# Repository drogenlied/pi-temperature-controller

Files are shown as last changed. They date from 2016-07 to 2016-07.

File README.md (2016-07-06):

# Pi temperature controller
A Raspberry Pi based H-bridge controller designed to stabilize temperatures in an optics lab

## Hardware
  * Raspberry Pi (Model 2 recommended)
  * Measurement Specialities TSYS01 temperature sensor
  * Adum 14xx isolators between control and driver
  * VNH3SP30 H-bridge driver for output
  
## Features
  * Can control Peltier elements as well as resistive heaters for temperature stabilisation.
  * Fabrication should be possible in every university PCB shop
  * Hand soldering is possible but reflowing the VNH3SP30 is recommended
  
## Software
Test software is in this repository but https://github.com/Ulm-IQO/qudi is recommended for operation.

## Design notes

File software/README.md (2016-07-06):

Required python modules:
  * spidev
  * i2cdev
  * RPi.GPIO

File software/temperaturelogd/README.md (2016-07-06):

# Modules

## Required Python 3 modules:
  * spidev
  * i2cdev
  * statistics

## optional:
  * influxdb

# /etc
Files in the etc folder need to have their paths modified to work for you!

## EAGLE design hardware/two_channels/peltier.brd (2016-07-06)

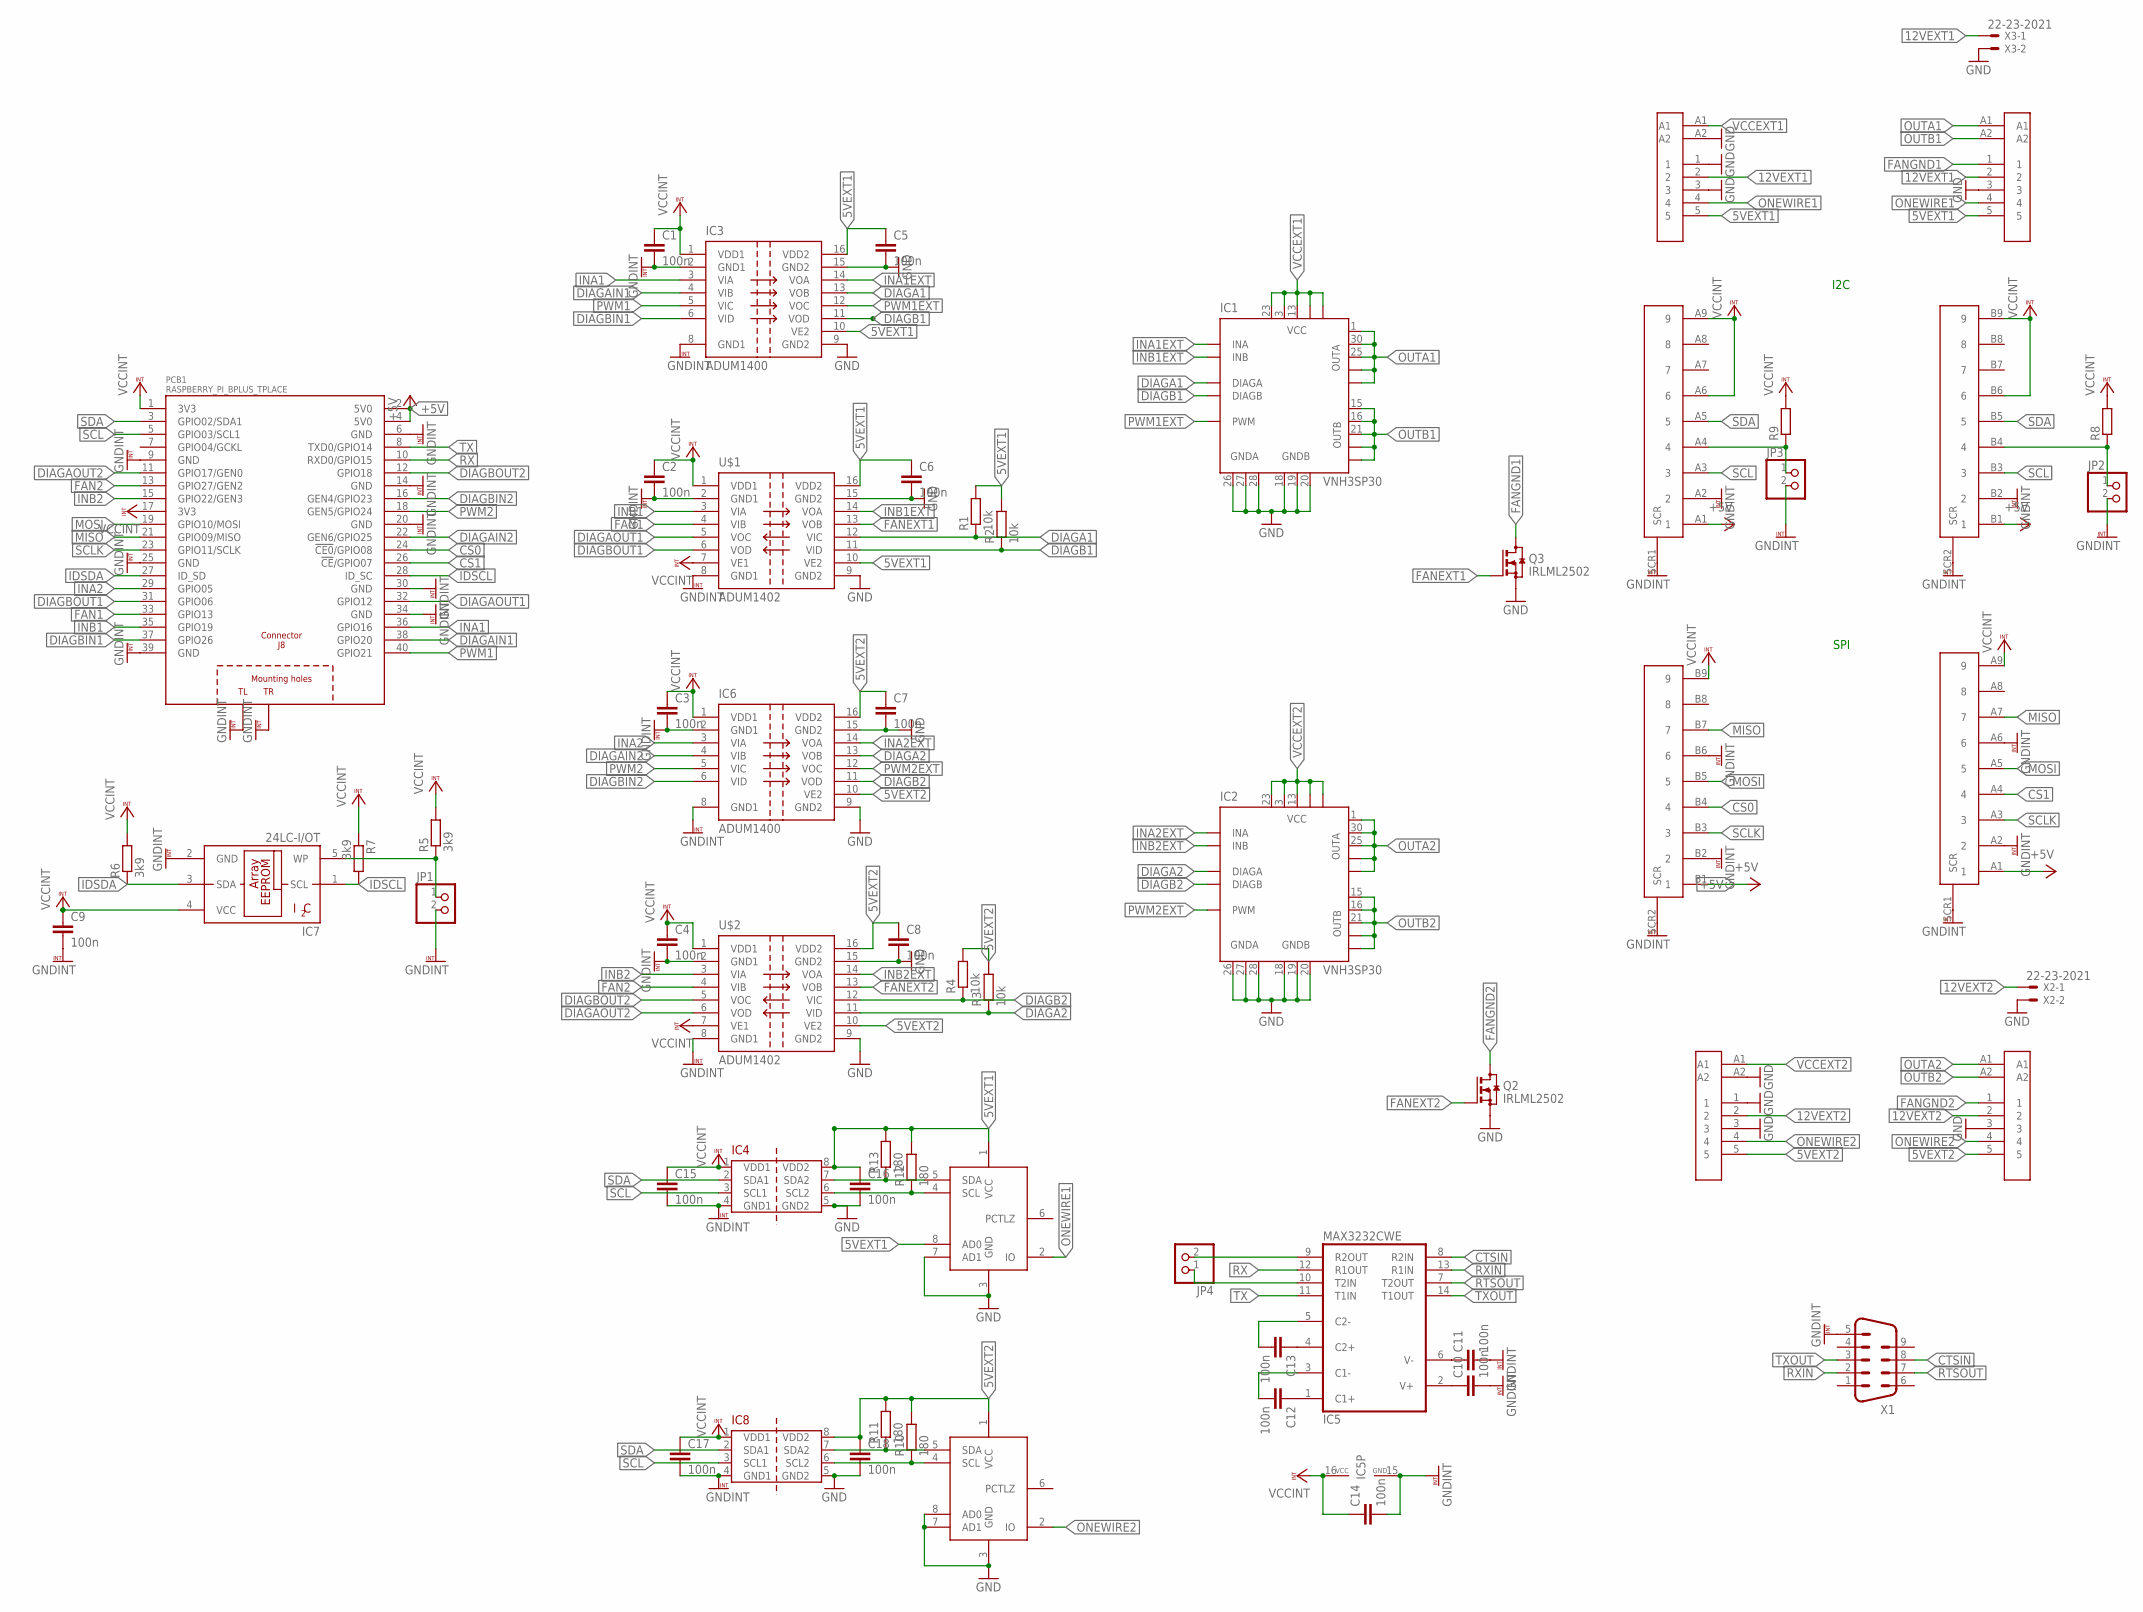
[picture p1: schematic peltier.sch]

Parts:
C1, C2, C3, C4, C5, C6, C7, C8, C9, C10, C11, C12, C13, C14, C15, C16, C17, C18: 100n; C0805
IC1, IC2: VNH3SP30; MULTIPOWERSO-30
IC3, IC6: ADUM1400; SO16W
IC4, IC8: ADUM1250; SO08
IC5: MAX3232CWE; SO16L
IC7: 24LC-I/OT; SOT23-5
JP1, JP2, JP3, JP4: PINHD-1X2; 1X02
PCB1: RASPBERRY_PI_BPLUS_TPLACE
Q2, Q3: IRLML2502; SOT23
R1, R2, R3, R4: 10k; R0805
R5, R6, R7: 3k9; R0805
R8, R9: R-EU_R0805; R0805
R10, R11, R12, R13: 180; R0805
U$1, U$2: ADUM1402; SO16W
U$3, U$4: 7W2-F
U$5, U$6: 7W2-M
U$11, U$12: 164A19919X
U$14, U$15: DS2483-100; SO-08
X1: M09HP
X2, X3: 22-23-2021

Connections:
5VEXT1: C5.1, C6.1, C16.1, IC3.10 (VE2), IC3.16 (VDD2), IC4.8 (VDD2), R1.2, R2.2, R12.2, R13.2, U$1.10 (VE2), U$1.16 (VDD2), U$3.5, U$5.5, U$14.1 (VCC), U$14.8 (AD0)
5VEXT2: C7.1, C8.1, C18.1, IC6.10 (VE2), IC6.16 (VDD2), IC8.8 (VDD2), R3.2, R4.2, R10.2, R11.2, U$2.10 (VE2), U$2.16 (VDD2), U$4.5, U$6.5, U$15.1 (VCC)
12VEXT1: U$3.2, U$5.2, X3.1
12VEXT2: U$4.2, U$6.2, X2.1
+5V: PCB1.2 (5V0), PCB1.4 (5V0), U$11.A1 (1), U$11.B1 (1), U$12.A1 (1), U$12.B1 (1)
CS0: PCB1.24 (!CE0!/GPIO08), U$12.B4 (4)
CS1: PCB1.26 (!CE!/GPIO07), U$12.A4 (4)
CTSIN: IC5.8 (R2IN), X1.8
DIAGA1: IC1.6 (DIAGA), IC3.13 (VOB), R1.1, U$1.12 (VIC)
DIAGA2: IC2.6 (DIAGA), IC6.13 (VOB), R3.1, U$2.11 (VID)
DIAGAIN1: IC3.4 (VIB), PCB1.38 (GPIO20)
DIAGAIN2: IC6.4 (VIB), PCB1.22 (GEN6/GPIO25)
DIAGAOUT1: PCB1.32 (GPIO12), U$1.5 (VOC)
DIAGAOUT2: PCB1.11 (GPIO17/GEN0), U$2.6 (VOD)
DIAGB1: IC1.10 (DIAGB), IC3.11 (VOD), R2.1, U$1.11 (VID)
DIAGB2: IC2.10 (DIAGB), IC6.11 (VOD), R4.1, U$2.12 (VIC)
DIAGBIN1: IC3.6 (VID), PCB1.37 (GPIO26)
DIAGBIN2: IC6.6 (VID), PCB1.16 (GEN4/GPIO23)
DIAGBOUT1: PCB1.31 (GPIO06), U$1.6 (VOD)
DIAGBOUT2: PCB1.12 (GPIO18), U$2.5 (VOC)
FAN1: PCB1.33 (GPIO13), U$1.4 (VIB)
FAN2: PCB1.13 (GPIO27/GEN2), U$2.4 (VIB)
FANEXT1: Q3.1 (G), U$1.13 (VOB)
FANEXT2: Q2.1 (G), U$2.13 (VOB)
FANGND1: Q3.3 (D), U$3.1
FANGND2: Q2.3 (D), U$4.1
GND: C5.2, C6.2, C7.2, C8.2, C16.2, C18.2, IC1.18 (GNDB), IC1.19 (GNDB), IC1.20 (GNDB), IC1.26 (GNDA), IC1.27 (GNDA), IC1.28 (GNDA), IC2.18 (GNDB), IC2.19 (GNDB), IC2.20 (GNDB), IC2.26 (GNDA), IC2.27 (GNDA), IC2.28 (GNDA), IC3.9 (GND2), IC3.15 (GND2), IC4.5 (GND2), IC6.9 (GND2), IC6.15 (GND2), IC8.5 (GND2), Q2.2 (S), Q3.2 (S), U$1.9 (GND2), U$1.15 (GND2), U$2.9 (GND2), U$2.15 (GND2), U$3.3, U$4.3, U$5.1, U$5.3, U$5.A2, U$6.1, U$6.3, U$6.A2, U$14.3 (GND), U$14.7 (AD1), U$15.3 (GND), U$15.7 (AD1), U$15.8 (AD0), X2.2, X3.2
GNDINT: C1.2, C2.2, C3.2, C4.2, C9.2, C10.2, C11.2, C14.2, C15.2, C17.2, IC3.2 (GND1), IC3.8 (GND1), IC4.4 (GND1), IC5.15 (GND), IC6.2 (GND1), IC6.8 (GND1), IC7.2 (GND), IC8.4 (GND1), JP1.2, JP2.2, JP3.2, PCB1.6 (GND), PCB1.9 (GND), PCB1.14 (GND), PCB1.20 (GND), PCB1.25 (GND), PCB1.30 (GND), PCB1.34 (GND), PCB1.39 (GND), PCB1.PE_TL (TL), PCB1.PE_TR (TR), U$1.2 (GND1), U$1.8 (GND1), U$2.2 (GND1), U$2.8 (GND1), U$11.A2 (2), U$11.B2 (2), U$11.SCR1 (SCR), U$11.SCR2 (SCR), U$12.A2 (2), U$12.A6 (6), U$12.B2 (2), U$12.B6 (6), U$12.SCR1 (SCR), U$12.SCR2 (SCR), X1.5
IDSCL: IC7.1 (SCL), PCB1.28 (ID_SC), R7.2
IDSDA: IC7.3 (SDA), PCB1.27 (ID_SD), R6.1
INA1: IC3.3 (VIA), PCB1.36 (GPIO16)
INA1EXT: IC1.5 (INA), IC3.14 (VOA)
INA2: IC6.3 (VIA), PCB1.29 (GPIO05)
INA2EXT: IC2.5 (INA), IC6.14 (VOA)
INB1: PCB1.35 (GPIO19), U$1.3 (VIA)
INB1EXT: IC1.11 (INB), U$1.14 (VOA)
INB2: PCB1.15 (GPIO22/GEN3), U$2.3 (VIA)
INB2EXT: IC2.11 (INB), U$2.14 (VOA)
MISO: PCB1.21 (GPIO09/MISO), U$12.A7 (7), U$12.B7 (7)
MOSI: PCB1.19 (GPIO10/MOSI), U$12.A5 (5), U$12.B5 (5)
unnamed: IC7.5 (WP), JP1.1, R5.1
unnamed: JP3.1, R9.1, U$11.A4 (4)
unnamed: JP2.1, R8.1, U$11.B4 (4)
unnamed: C10.1, IC5.2 (V+)
unnamed: C11.1, IC5.6 (V-)
unnamed: C12.1, IC5.1 (C1+)
unnamed: C12.2, IC5.3 (C1-)
unnamed: C13.1, IC5.4 (C2+)
unnamed: C13.2, IC5.5 (C2-)
unnamed: IC5.9 (R2OUT), JP4.2
unnamed: IC5.10 (T2IN), JP4.1
unnamed: IC4.7 (SDA2), R13.1, U$14.5 (SDA)
unnamed: IC4.6 (SCL2), R12.1, U$14.4 (SCL)
unnamed: IC8.7 (SDA2), R11.1, U$15.5 (SDA)
unnamed: IC8.6 (SCL2), R10.1, U$15.4 (SCL)
ONEWIRE1: U$3.4, U$5.4, U$14.2 (IO)
ONEWIRE2: U$4.4, U$6.4, U$15.2 (IO)
OUTA1: IC1.1 (OUTA), IC1.25 (OUTA), IC1.30 (OUTA), IC1.OUTA, IC1.OUTA@1 (OUTA), U$3.A1
OUTA2: IC2.1 (OUTA), IC2.25 (OUTA), IC2.30 (OUTA), IC2.OUTA, IC2.OUTA@1 (OUTA), U$4.A1
OUTB1: IC1.15 (OUTB), IC1.16 (OUTB), IC1.21 (OUTB), IC1.OUTB, IC1.OUTB@1 (OUTB), U$3.A2
OUTB2: IC2.15 (OUTB), IC2.16 (OUTB), IC2.21 (OUTB), IC2.OUTB, IC2.OUTB@1 (OUTB), U$4.A2
PWM1: IC3.5 (VIC), PCB1.40 (GPIO21)
PWM1EXT: IC1.8 (PWM), IC3.12 (VOC)
PWM2: IC6.5 (VIC), PCB1.18 (GEN5/GPIO24)
PWM2EXT: IC2.8 (PWM), IC6.12 (VOC)
RTSOUT: IC5.7 (T2OUT), X1.7
RX: IC5.12 (R1OUT), PCB1.10 (RXD0/GPIO15)
RXIN: IC5.13 (R1IN), X1.2
SCL: IC4.3 (SCL1), IC8.3 (SCL1), PCB1.5 (GPIO03/SCL1), U$11.A3 (3), U$11.B3 (3)
SCLK: PCB1.23 (GPIO11/SCLK), U$12.A3 (3), U$12.B3 (3)
SDA: IC4.2 (SDA1), IC8.2 (SDA1), PCB1.3 (GPIO02/SDA1), U$11.A5 (5), U$11.B5 (5)
TX: IC5.11 (T1IN), PCB1.8 (TXD0/GPIO14)
TXOUT: IC5.14 (T1OUT), X1.3
VCCEXT1: IC1.3 (VCC), IC1.13 (VCC), IC1.23 (VCC), IC1.VCC, IC1.VCC@1 (VCC), U$5.A1
VCCEXT2: IC2.3 (VCC), IC2.13 (VCC), IC2.23 (VCC), IC2.VCC, IC2.VCC@1 (VCC), U$6.A1
VCCINT: C1.1, C2.1, C3.1, C4.1, C9.1, C14.1, C15.1, C17.1, IC3.1 (VDD1), IC4.1 (VDD1), IC5.16 (VCC), IC6.1 (VDD1), IC7.4 (VCC), IC8.1 (VDD1), PCB1.1 (3V3), PCB1.17 (3V3), R5.2, R6.2, R7.1, R8.2, R9.2, U$1.1 (VDD1), U$1.7 (VE1), U$2.1 (VDD1), U$2.7 (VE1), U$11.A6 (6), U$11.A9 (9), U$11.B6 (6), U$11.B9 (9), U$12.A9 (9), U$12.B9 (9)

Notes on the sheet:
I2C
SPI

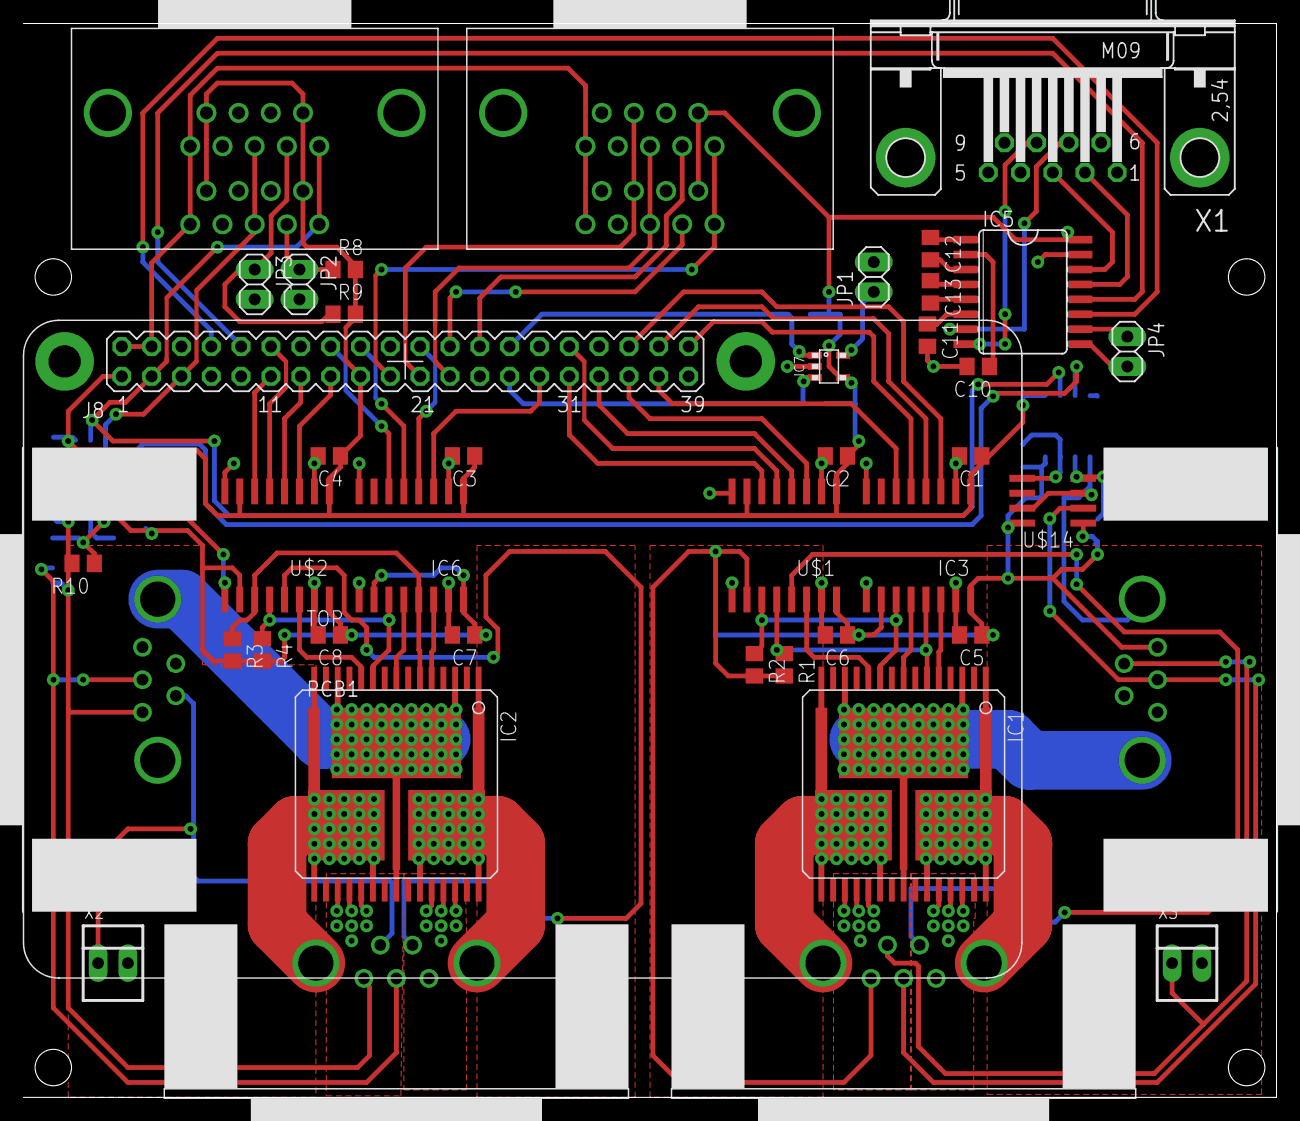
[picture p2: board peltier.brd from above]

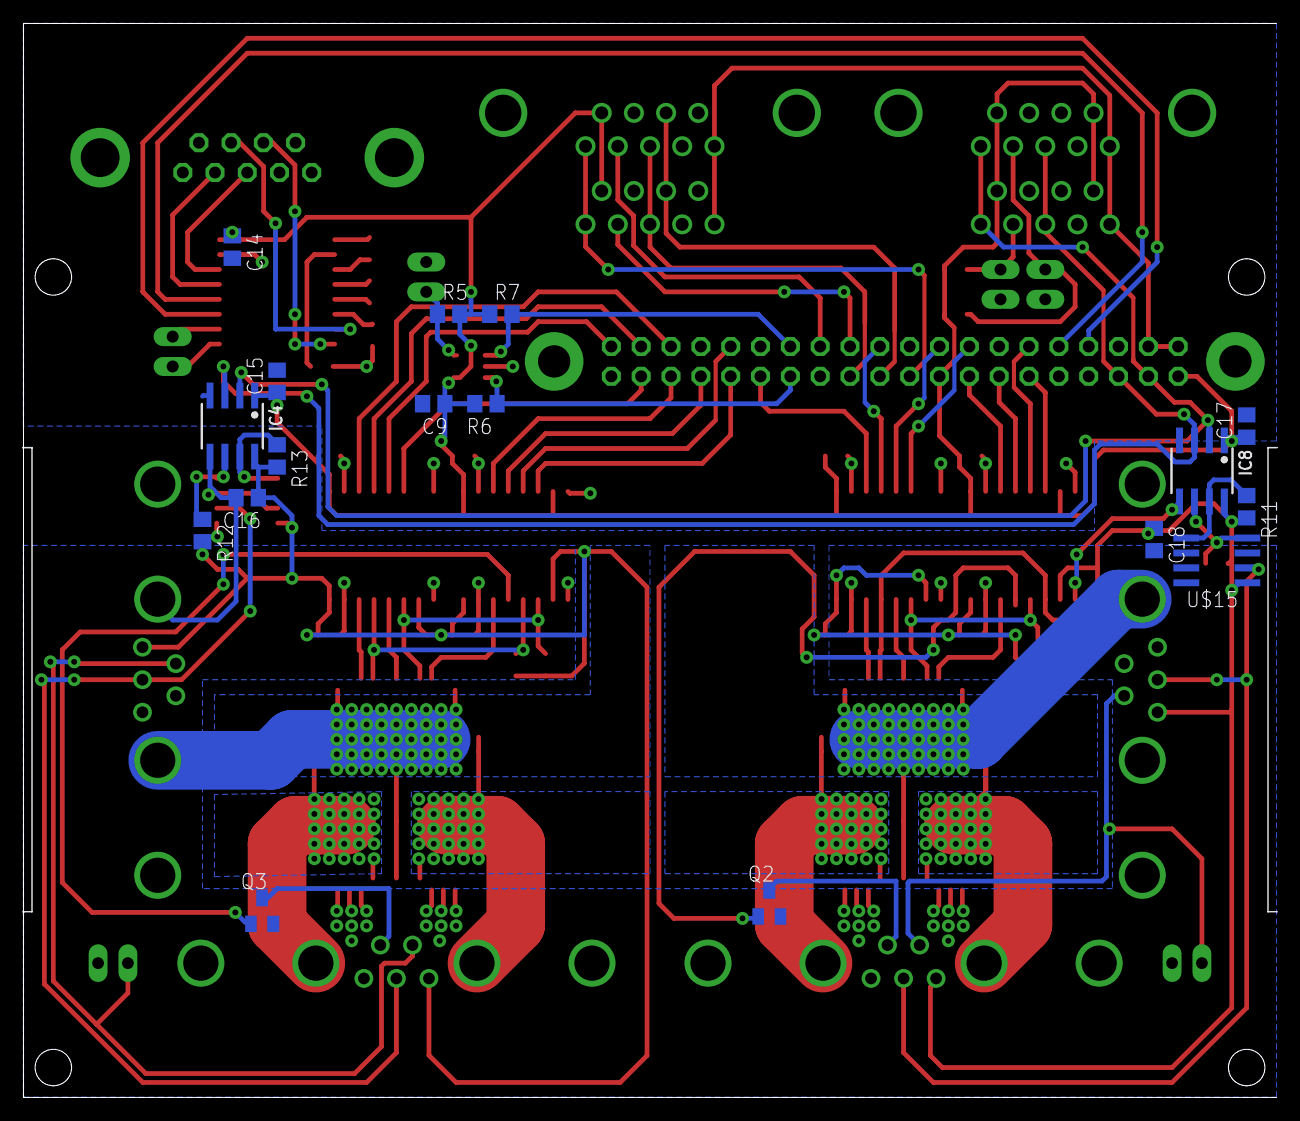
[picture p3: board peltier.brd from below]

Board: 2 copper layers, 106.7 x 91.4 mm, 59 parts (17 on the bottom side), 76 nets.

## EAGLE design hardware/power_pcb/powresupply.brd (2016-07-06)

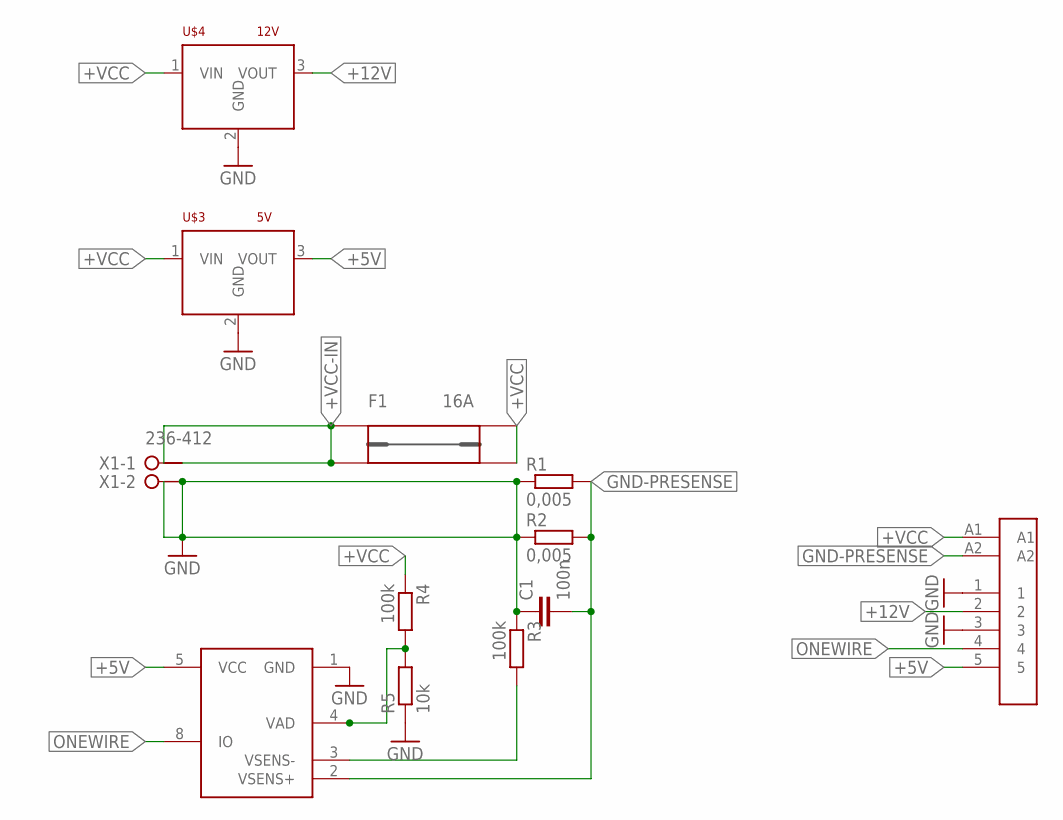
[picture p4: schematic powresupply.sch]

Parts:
C1: 100n; C0805
F1: 16A; 1A3400
R1, R2: 0,005; R2512
R3, R4: 100k; R0805
R5: 10k; R0805
U$1: 7W2-F
U$2: DS2438; SO-08
U$3: 5V; RECOM
U$4: 12V; RECOM
X1: 236-412

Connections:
+5V: U$1.5, U$2.5 (VCC), U$3.3 (VOUT)
+12V: U$1.2, U$4.3 (VOUT)
+VCC: F1.P$3, F1.P$4, R4.1, U$1.A1, U$3.1 (VIN), U$4.1 (VIN)
+VCC-IN: F1.P$1, F1.P$2, X1.1@1 (KL1), X1.1@2 (KL2)
GND: C1.1, R1.1, R2.1, R3.1, R5.1, U$1.1, U$1.3, U$2.1 (GND), U$3.2 (GND), U$4.2 (GND), X1.2@1 (KL1), X1.2@2 (KL2)
GND-PRESENSE: C1.2, R1.2, R2.2, U$1.A2, U$2.2 (VSENS+)
unnamed: R4.2, R5.2, U$2.4 (VAD)
unnamed: R3.2, U$2.3 (VSENS-)
ONEWIRE: U$1.4, U$2.8 (IO)

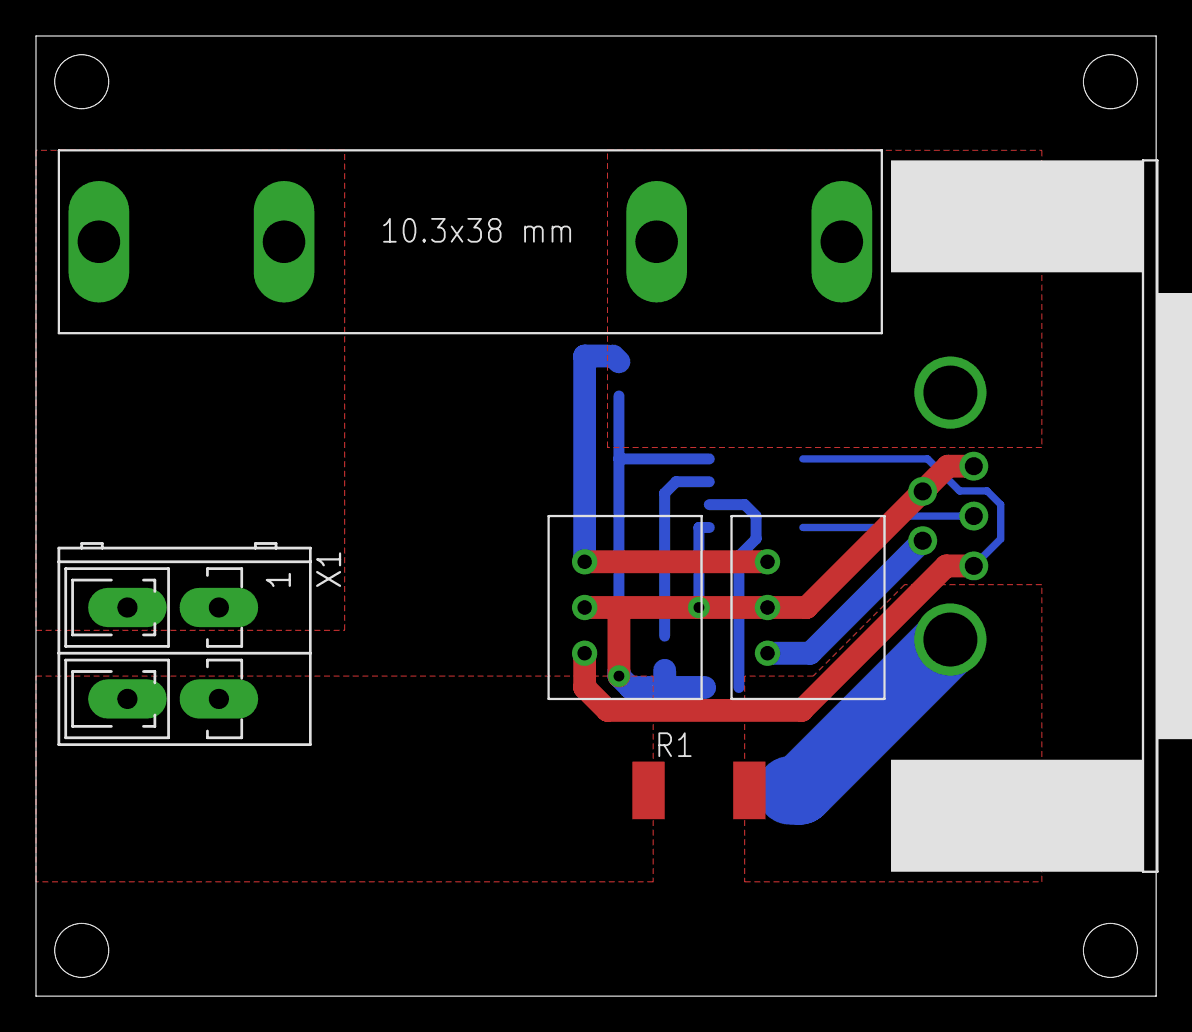
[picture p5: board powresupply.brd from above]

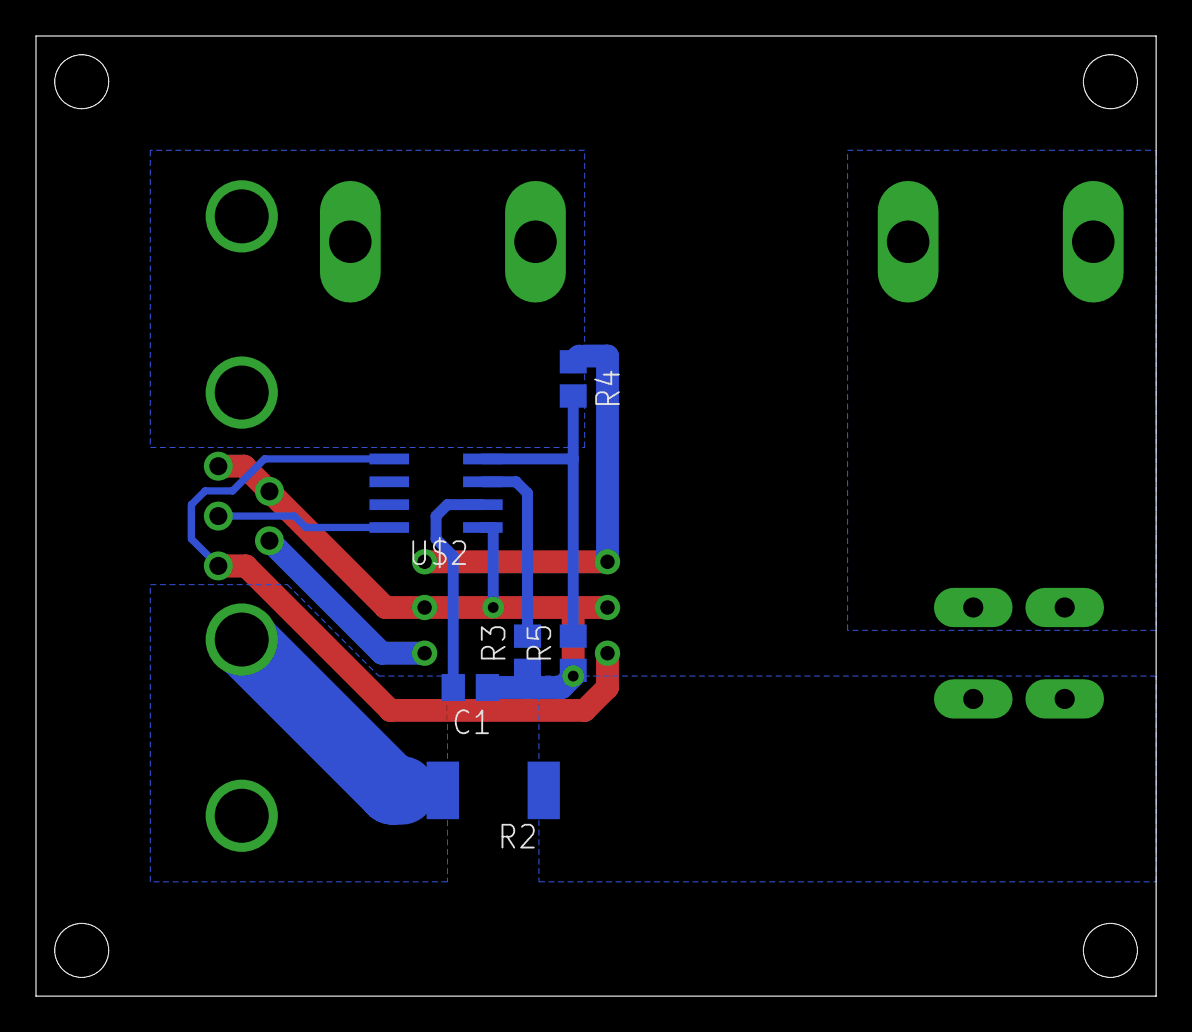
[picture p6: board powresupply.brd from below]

Board: 2 copper layers, 62.2 x 53.3 mm, 12 parts (6 on the bottom side), 9 nets.

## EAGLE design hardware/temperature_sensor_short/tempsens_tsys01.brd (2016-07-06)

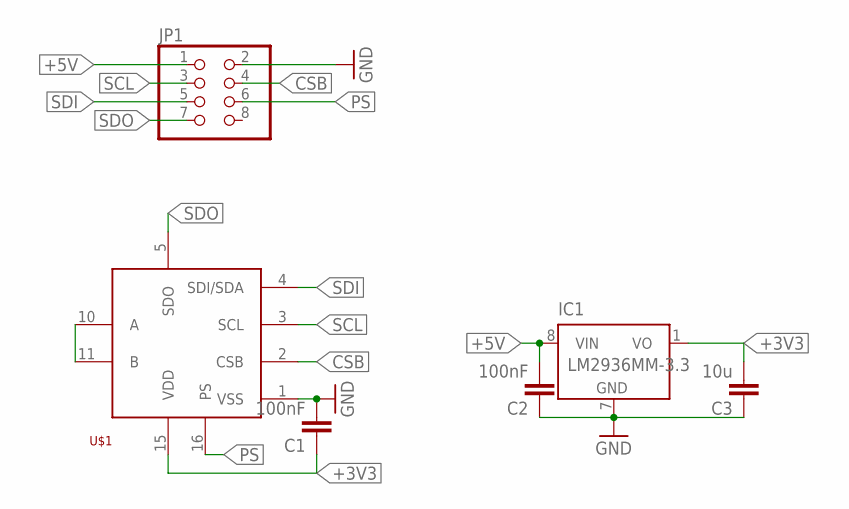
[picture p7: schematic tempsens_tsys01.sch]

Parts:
C1, C2: 100nF; C0603K
C3: 10u; C0805
IC1: LM2936MM-3.3; MINI-SO8
JP1: PINHD-2X4_2.00; 2X04M
U$1: TSYS01NOPAD; TSYS01_NOPAD

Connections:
+3V3: C1.1, C3.2, IC1.1 (VO), U$1.15 (VDD)
+5V: C2.2, IC1.8 (VIN), JP1.1
CSB: JP1.4, U$1.2 (CSB)
GND: C1.2, C2.1, C3.1, IC1.7 (GND), JP1.2, U$1.1 (VSS)
unnamed: U$1.10 (A), U$1.11 (B)
PS: JP1.6, U$1.16 (PS)
SCL: JP1.3, U$1.3 (SCL)
SDI: JP1.5, U$1.4 (SDI/SDA)
SDO: JP1.7, U$1.5 (SDO)

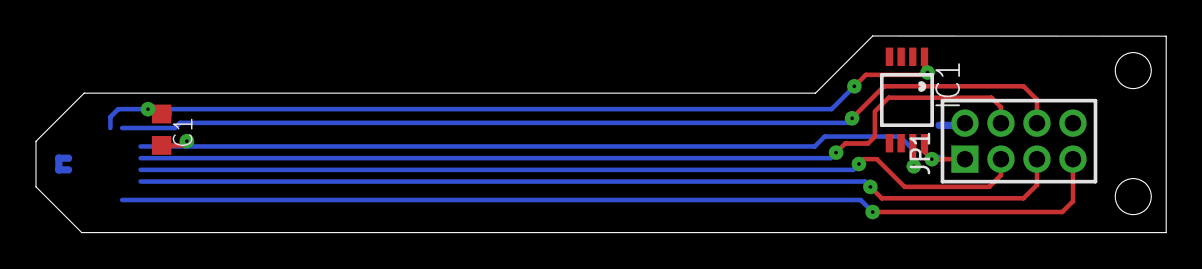
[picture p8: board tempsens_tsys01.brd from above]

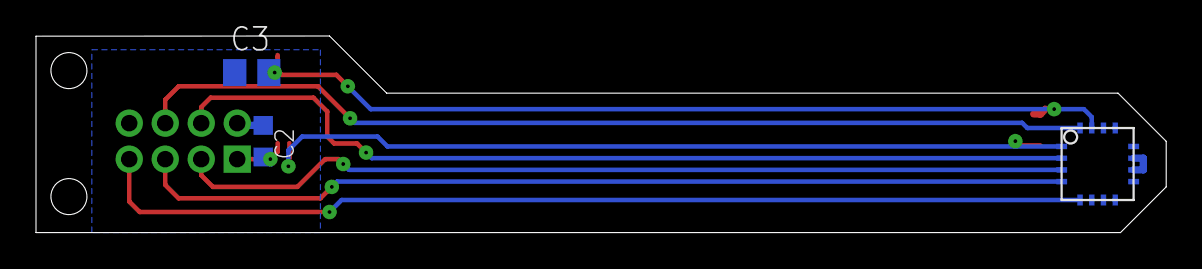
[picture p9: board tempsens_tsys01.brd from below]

Board: 2 copper layers, 62.8 x 10.9 mm, 6 parts (3 on the bottom side), 9 nets.

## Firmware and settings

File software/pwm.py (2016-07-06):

#!/usr/bin/env python3
# -*- coding: utf-8 -*-

import time
import sys
import RPi.GPIO as GPIO
import diag

class PWM():

    def __init__(self, right=True):
        if right:
            self.inapin = 16
            self.inbpin = 19
            self.pwmpin = 21
            self.enapin = 20
            self.enbpin = 26
            self.diapin = 12
            self.dibpin = 6
            self.fanpin = 13
        else:
            self.inapin = 5
            self.inbpin = 22
            self.pwmpin = 24
            self.enapin = 25
            self.enbpin = 23
            self.diapin = 17
            self.dibpin = 18
            self.fanpin = 27

        self.freq = 10

    def setup(self):
        GPIO.setmode(GPIO.BCM)
        GPIO.setup(self.enapin, GPIO.OUT)
        GPIO.setup(self.enbpin, GPIO.OUT)
        GPIO.setup(self.inapin, GPIO.OUT)
        GPIO.setup(self.inbpin, GPIO.OUT)
        GPIO.setup(self.pwmpin, GPIO.OUT)
        GPIO.setup(self.fanpin, GPIO.OUT)
        GPIO.setup(self.diapin, GPIO.IN)
        GPIO.setup(self.dibpin, GPIO.IN)
        self.p = GPIO.PWM(self.pwmpin, self.freq)

    def start(self):
        GPIO.output(self.fanpin, True)
        GPIO.output(self.enapin, True)
        GPIO.output(self.enbpin, True)
        GPIO.output(self.inapin, True)
        GPIO.output(self.inbpin, False)

        # Setup PWM and DMA channel 0
        self.p.start(0)

    def stop(self):
        # Stop PWM
        self.p.stop()
        GPIO.output(self.enapin, False)
        GPIO.output(self.enbpin, False)
        GPIO.output(self.inapin, False)
        GPIO.output(self.inbpin, False)
        GPIO.output(self.fanpin, False)

    def change(self, duty):        
        if duty >= 0:
            GPIO.output(self.inapin, True)
            GPIO.output(self.inbpin, False)
        else:
            GPIO.output(self.inapin, False)
            GPIO.output(self.inbpin, True)
        self.p.ChangeDutyCycle(abs(duty))

if __name__ == '__main__':
    diag.diag()

    side = len(sys.argv) >= 2 and sys.argv[1] == 'right'
        
    p1 = PWM(side)

    p1.setup()
    diag.diag()

    p1.start()
    print("full forward")
    p1.change(100)
    time.sleep(30)
    print("full backward")
    p1.change(-100)
    time.sleep(30)

    p1.stop()

    diag.diag()

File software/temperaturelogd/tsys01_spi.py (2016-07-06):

#!/usr/bin/env python3
# -*- coding: utf-8 -*-
try:
    from influxdb import InfluxDBClient
except:
    pass
import statistics
import datetime
import bitarray
import getopt
import spidev
import struct
import signal
import time
import math
import sys

def reversebits(bits):
    b = bitarray.bitarray()
    b.frombytes(bytes([bits]))
    b.reverse()
    return struct.unpack('B', b.tobytes())[0]

class TSYS01:
    READ_ADC  = 0x00
    RESET     = 0x1E
    START_ADC = 0x48
    READ_ROM0 = 0xA0

    def __init__(self, bus = 0, device = 0):
        self.bus = bus
        self.device = device
        self.rom = []
        self.spi = spidev.SpiDev()

    def diag(self):
        print('==== SPI Diagnostics ====')
        print('Bits per word: {:>10}'.format(self.spi.bits_per_word))
        print('CS is active high: {!s:>6}'.format(self.spi.cshigh))
        print('Loopback: {!s:>15}'.format(self.spi.loop))
        print('LSB first: {!s:>14}'.format(self.spi.lsbfirst))
        print('Max clock speed: {:>8}'.format(self.spi.max_speed_hz))
        print('Clock mode: {:>13}'.format(self.spi.mode))
        print('SI/SO shared: {!s:>11}'.format(self.spi.threewire))
        print('=========================')

    def open(self):
        self.spi.open(self.bus, self.device)
        #self.spi.max_speed_hz = 8000
        #self.diag()
        
    def close(self):
        self.spi.close()

    def reset(self):
        #print('Reset: {:x} MSB: {:x}'.format(self.RESET, reversebits(self.RESET)))
        rbuf = self.spi.xfer( [self.RESET], 8000, 3000 )
        #for i in rbuf:
        #    print('read: {:x} LSB: {:x}'.format(i, reversebits(i)))
        time.sleep(0.003)
        #time.sleep(1)

    def readRomAddr(self, addr):
        bytes = self.READ_ROM0 | 0x0F & ( addr << 1)
        #print('Read ROM: {:x} MSB: {:x} '.format(bytes, reversebits(bytes)))
        rbuf = self.spi.xfer( [bytes, 0x00, 0x00] )
        #for i in rbuf:
        #    print('read: {:x} LSB: {:x}'.format(i, reversebits(i)))
        #time.sleep(0.5)
        #print(rbuf[1:])
        return 2**8*rbuf[1] + rbuf[2]

    def readRom(self):
        self.rom = []
        for i in range(8):
            self.rom.append(self.readRomAddr(i))
        
    def startADC(self):
        try:
            #print('Start ADC: {:x} MSB: {:x} '.format(self.START_ADC, reversebits(self.START_ADC)))
            rbuf = self.spi.xfer([self.START_ADC])
            #for i in rbuf:
            #    print('read: {:x} LSB: {:x}'.format(i, reversebits(i)))
        except OSError:
            pass
        time.sleep(0.010)

    def readADC(self):
        #print('Read ADC: {:x} MSB: {:x} '.format(self.READ_ADC, reversebits(self.READ_ADC)))
        rbuf = self.spi.xfer([self.READ_ADC, 0x00, 0x00, 0x00] )
        #for i in rbuf:
        #    print('read: {:x} LSB: {:x}'.format(i, reversebits(i)))
        return struct.unpack('>I', b'\0' + bytes(rbuf[1:]))[0]

    def temperatureCelsius(self, adcValue):
        if len(self.rom) < 8:
            self.readRom()
        adc16 = adcValue / 2**8
        return (-2.0 * self.rom[1] * 10**-21 * adc16**4
              +  4.0 * self.rom[2] * 10**-16 * adc16**3
              + -2.0 * self.rom[3] * 10**-11 * adc16**2
              +  1.0 * self.rom[4] * 10**-6  * adc16
              + -1.5 * self.rom[5] * 10**-2 );

    def temperatureKelvin(self, adcValue):
        return 273.15 + self.temperatureCelsius(adcValue)

# Generates the necessary payload to post
# temperature data into the InfluxDB
def temperature_data(temperature, variance):
    return [
        {
             'measurement': 'Temperature',
             'fields': {
                 'degrees_celsius': temperature,
                 'standard_deviation': variance},
              'tags': {
                  'sensor': 'TSYS01',
                  'host': 'qo030'}
        }]

if __name__ == '__main__':
    opts, args = getopt.getopt(
                    sys.argv[1:],
                    'a:b:cdf:hi:n:N:v',
                    [
                        'address',
                        'bus',
                        'client',
                        'daemon',
                        'file',
                        'help',
                        'interval',
                        'number',
                        'average-number',
                        'verbose'
                    ]
                 )

    daemon = False
    bus = 0
    address = 0
    verbose = False
    n = 10
    avg = 1
    interval = 1.0
    outfile = sys.stdout
    influxClient = None

    for o, a in opts:
        if o in ('-a', '--address'):
            address = int(a)
        elif o in ('-b', '--bus'):
            bus = int(a)
        elif o in ('-d', '--daemon'):
            daemon = True
            n = 1
        elif o in ('-f', '--file'):
            try:
                outfile = open(a, 'a')
            except:
                outfile = sys.stdout
        elif o in ('-h', '--help'):
            print('Usage: {0} [-b bus] [-a device address] [-d] [-h]'.format(sys.argv[0]))
            print('-a address: spi device address number')
            print('-b bus: bus number')
            print('-d: run as daemon')
            print('-h: show help')
            print('')
            sys.exit()
        elif o in ('-i', '--interval'):
            interval = float(a)
        elif o in ('-n', '--number'):
            n = int(a)
        elif o in ('-N', '--average-number'):
           avg = int(a)
        elif o in ('-v', '--verbose'):
            verbose = True
        elif o in ('-c', '--client'):
            daemon = True
            influxClient = InfluxDBClient('localhost', 8086, 'user', 'password', 'database')
        else:
            print('Usage: {0} [-b bus] [-a device address] [-d] [-h]'.format(sys.argv[0], ))
            sys.exit(1)

    def sighandler(signal, frame):
        print('Terminating.', file=sys.stderr)
        sys.exit(0)
    signal.signal(signal.SIGTERM, sighandler)
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

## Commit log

2016-07-06 raspberry pi hat eeprom files
2016-07-06 software controlling temperature sensors and power driver
2016-07-06 add hardware design for temperature controller project
    [peltier.brd, peltier.sch, powresupply.brd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]
